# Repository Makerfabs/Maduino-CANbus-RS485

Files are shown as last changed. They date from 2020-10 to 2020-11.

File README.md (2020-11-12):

# Maduino Zero CANBUS
## Introduce

CAN-BUS is a common industrial communication bus because of its long travel distance, medium communication speed, and high reliability, it is the backbone of many protocols with applications in automation, industrial systems, building management. This Maduino Zero CAN-BUS based on SAMD21G18A, with the CAN controller MCP2515 and CAN transceiver MAX3051, to create a ready-to-use CAN-bus port. With this board, you can easily get/send your local data remotely with a standard CAN Bus. For example, you can collect local sensor data, using the Maduino zero ports, and send all the data to remote servers, to create remote-monitor with reliable CAN-Bus communication.<br>
[Makerfabs Wiki](https://www.makerfabs.com/wiki/index.php?title=Maduino_Zero_Canbus_with_RS485) <br>
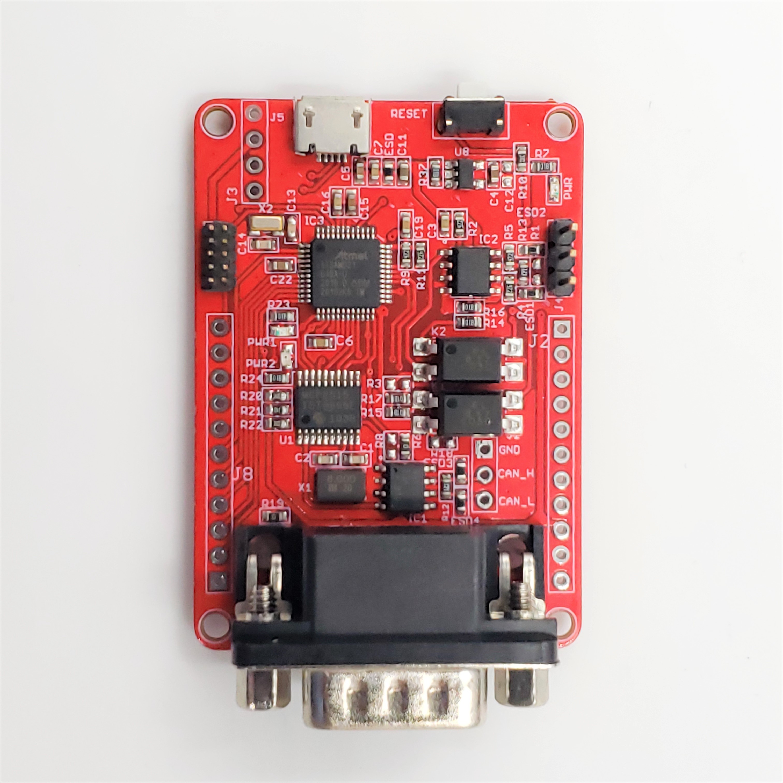
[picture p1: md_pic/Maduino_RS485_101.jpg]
<br/>

## Features

* ATMEL SAMD21G18A: 32-bit ARM® Cortex®-M0, Arduino Zero bootloader pre-loaded.<br>
* CAN-BUS/ RS-485.<br>
* Implements CAN V2.0 at 1M/s.<br>
* MCP2515 CAN Bus controller and MAX3051 CAN Bus transceiver.<br>
* Allows for Transmission Speeds Up to 16Mbps of RS-485.<br>
* Industrial standard 9 pins sub-D connector.<br>

## Usage

### Software setup

* After installed Arduino, there is no package to support the board (Arduino zero) that is needed to be installed.<br>
* select tools ->Board -> Board Manager, search "Arduino zero" and install "Arduino SAMD Boards".<br>
* Select Tools ->Board -> Arduino Zero (Native USB Port), select Tools -> Port -> com…<br>

### Test

* The sensors or devices which can carry on RS485 or CANbus are connected to the board through cables. in this project, use the same board instead of the device being tested, and connected two board by cables or Dupont Lines to check the communication between boards.<br>
* The pins connection is:<br>

|Maduino Zero CANbus with RS485 |Devices or sensors |
|---|---|
|GND |GND |
|RS485_A |RS485_A |
|RS485_B |RS485_B |
|CAN_H | CAN_H |
|CAN_L | CAN_L |

#### CANBUS
* One board upload the [CAN_Sender.ino](https://github.com/Makerfabs/Maduino-CANbus-RS485/blob/main/CAN_Sender/CAN_Sender.ino) , and the other upload the [CAN_Receiver.ino](https://github.com/Makerfabs/Maduino-CANbus-RS485/blob/main/CAN_Receiver/CAN_Receiver.ino). Both programs include the functions which can realize receiving and sending data in RS485 communication mode and CANBUS communication mode.<br>
* After the upload is successful, open the Serial Monitor and you can observe that the board is receiving and sending data cyclically through CANBUS. The green indicator light on the board will flash when data is received.<br>

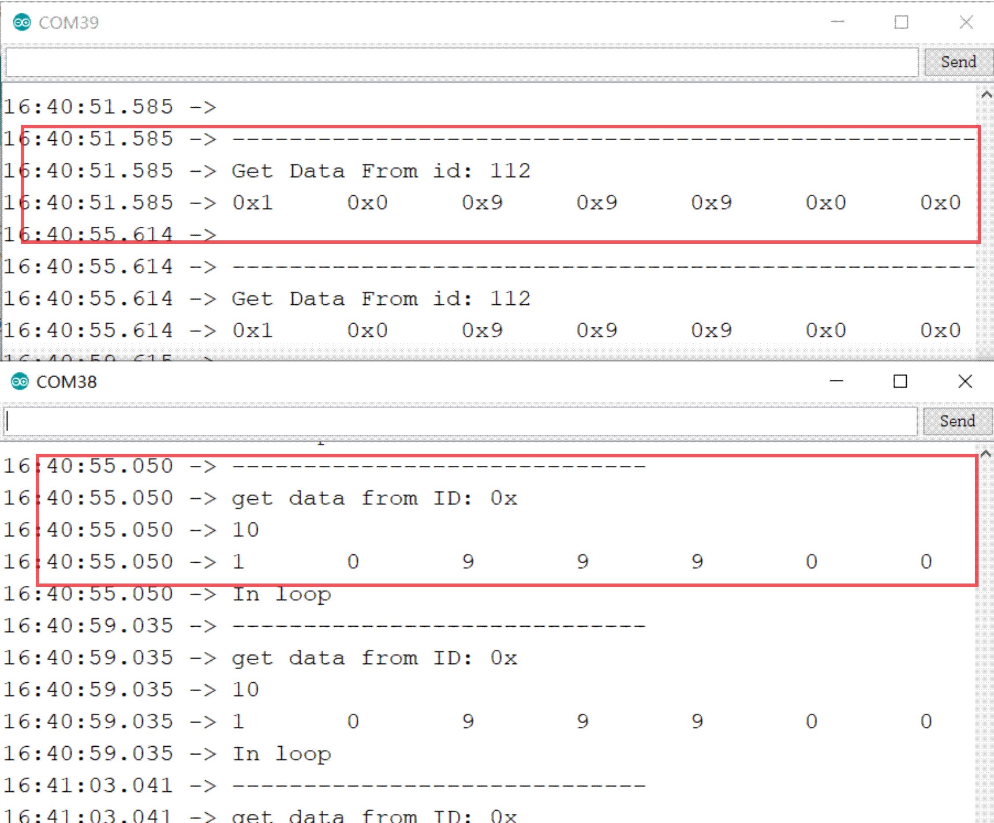
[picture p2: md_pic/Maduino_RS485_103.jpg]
<br/>

#### RS485
* Two boards upload the [RS485.ino](https://github.com/Makerfabs/Maduino-CANbus-RS485/blob/main/RS485/RS485.ino) ,
* After the upload is successful, open the Serial Monitor and send data through the Serial Monitor, and receive the data through RS485 communication on another board. The blue indicator light on the board will flash when data is received.<br>

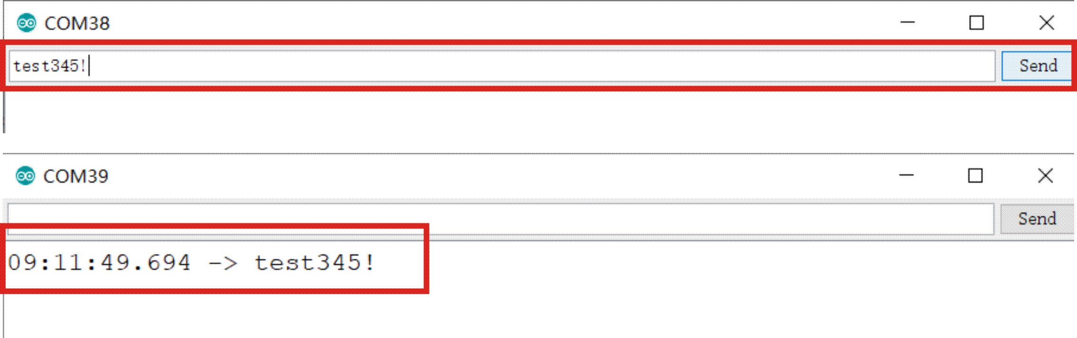
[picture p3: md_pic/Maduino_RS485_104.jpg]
<br/>
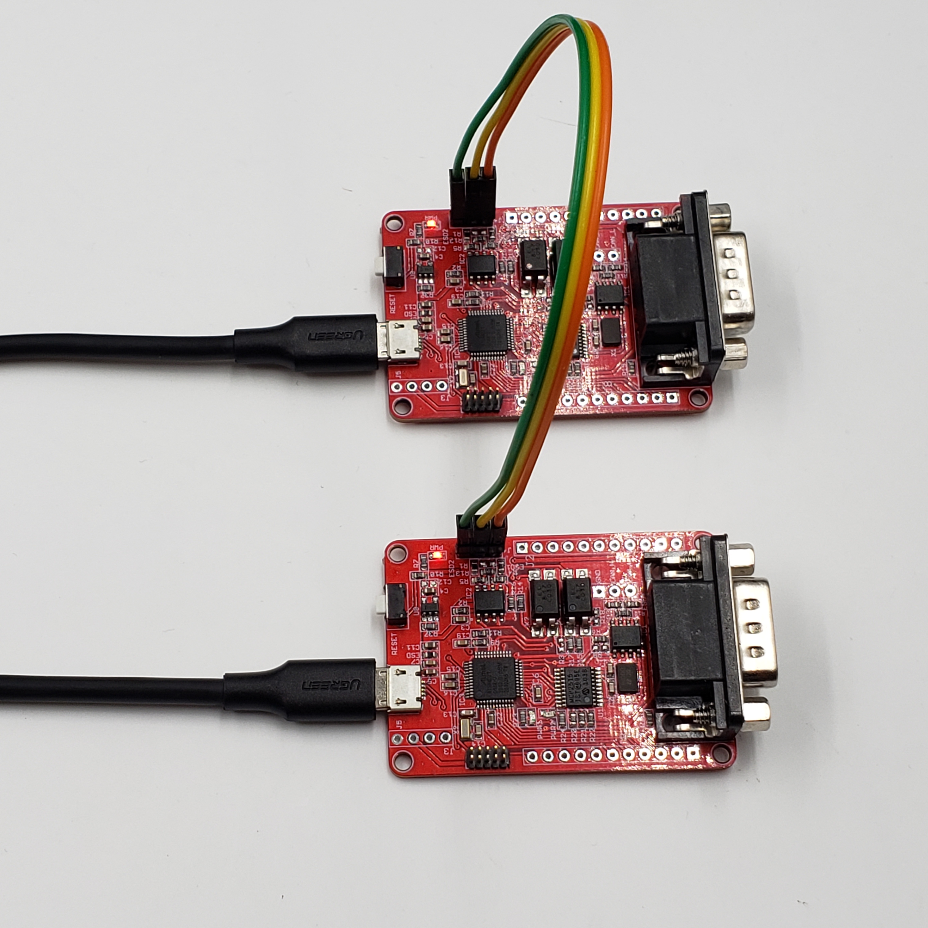
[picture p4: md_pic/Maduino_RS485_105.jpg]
<br/>

#### TEST_DHT11_OLED

This project is about data transmission via CANBUS. Use Maduino Zero CANBUS to collect temperature and humidity data and send it through CANBUS, and use the same module to receive and display the data.

<br/>

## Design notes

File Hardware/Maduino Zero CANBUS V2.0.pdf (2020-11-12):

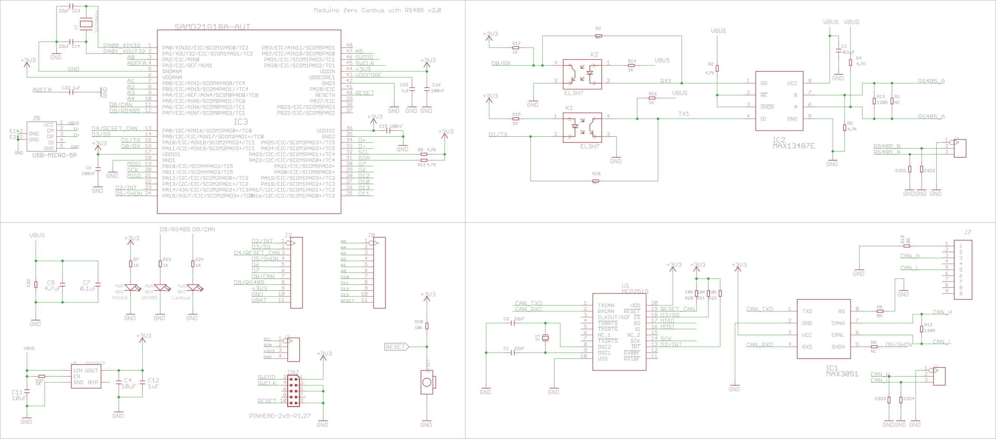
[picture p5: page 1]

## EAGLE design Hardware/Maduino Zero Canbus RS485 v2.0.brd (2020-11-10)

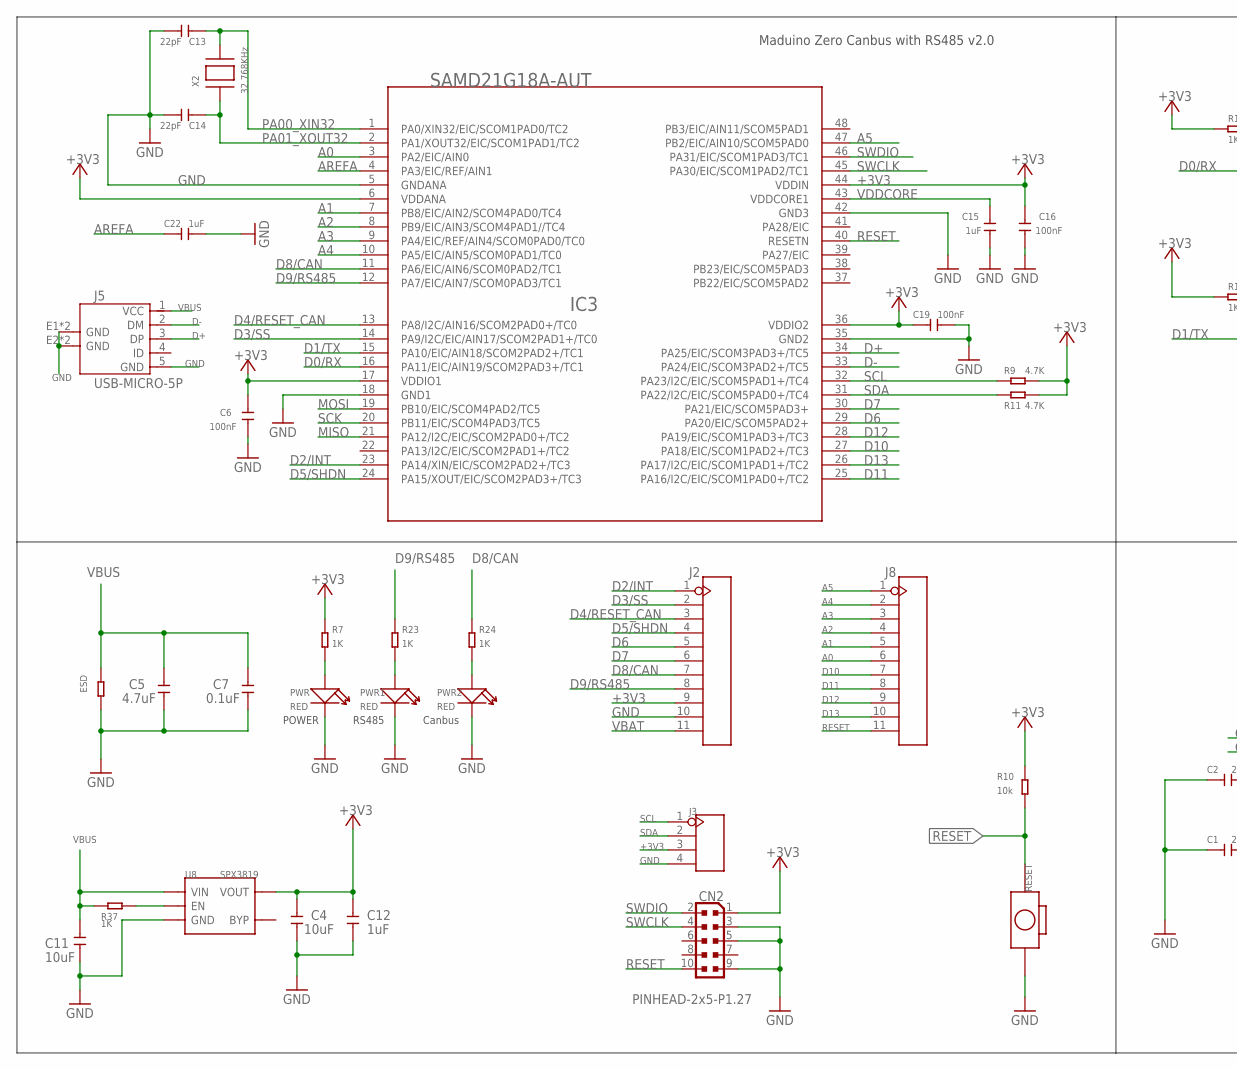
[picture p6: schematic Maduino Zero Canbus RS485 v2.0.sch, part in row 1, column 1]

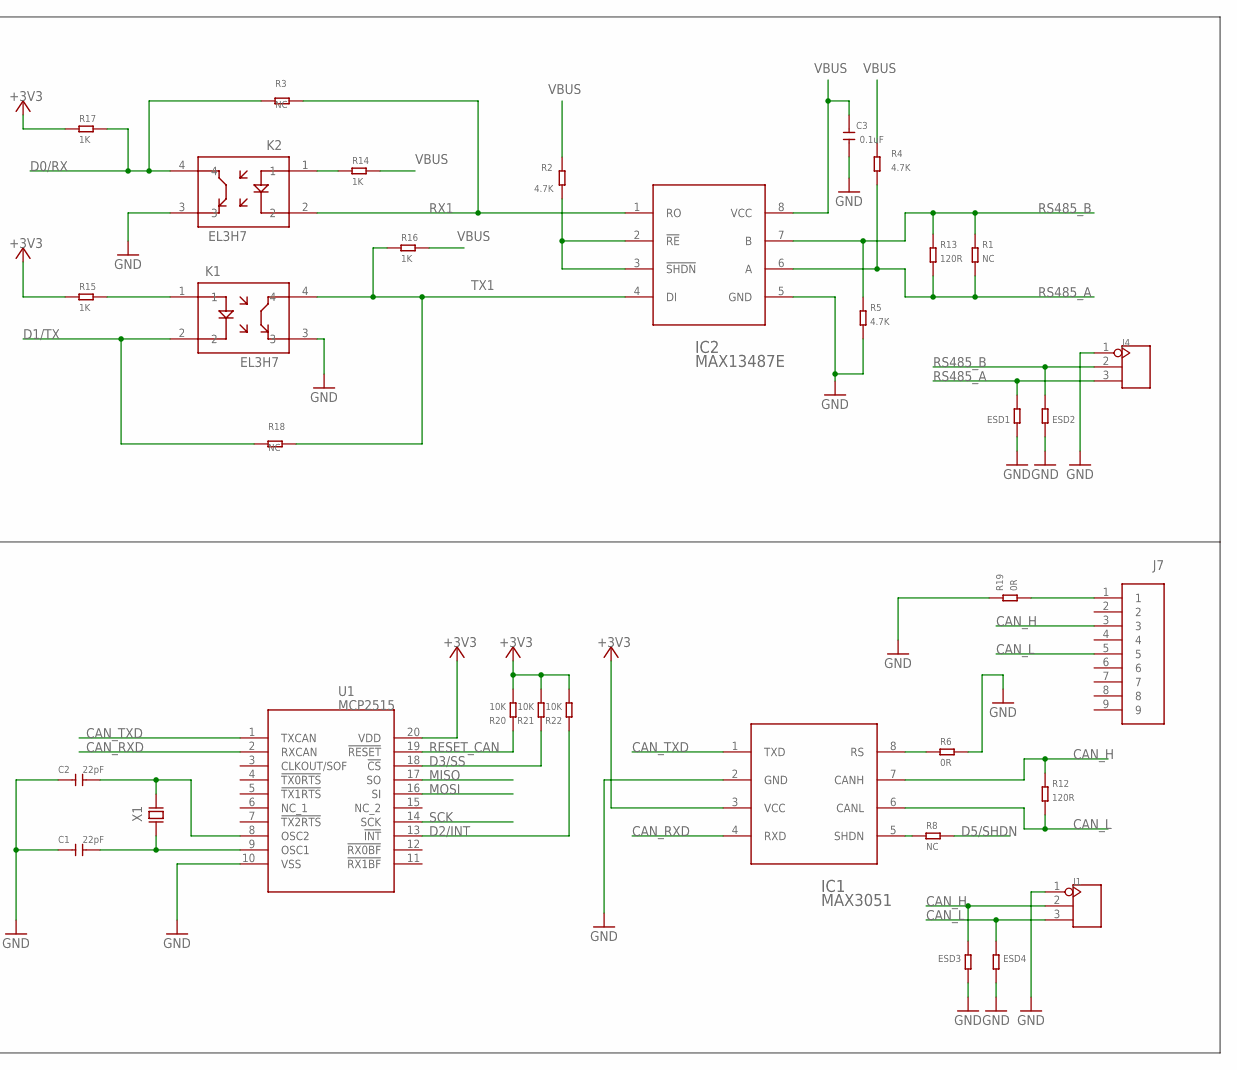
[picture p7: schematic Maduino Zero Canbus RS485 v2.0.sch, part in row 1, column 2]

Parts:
C1, C2, C13, C14: 22pF; 0603
C3, C7: 0.1uF; 0603
C4, C11: 10uF; 0603
C5: 4.7uF; 0603
C6, C16, C19: 100nF; 0603
C12, C15, C22: 1uF; 0603
CN2: PINHEAD-2x5-P1.27; PINHEAD_2X05_127
ESD, ESD1, ESD2: R-0603; R0603
ESD3, ESD4: NC; R0603
IC1: MAX3051; DIP8_MX3051
IC2: MAX13487E; DIP8_MAX13487
IC3: SAMD21G18A-AUT; TQFP48-7X7
J1, J4: HEADER-3P-2.54; 3P-2.54
J2, J8: HEADER-11P-2.54; 11P-2.54
J3: HEADER-4P-60/35MILROUND; 4P-65/35ROUND
J5: USB-MICRO-5P; MICRO-USB-5P
J7: DB9-90; DIP9-DB9-P2.77
K1, K2: EL3H7; SOP-4_P1.27
PWR, PWR1, PWR2: RED; LED-0603
R1, R3, R8, R18: NC; R0603
R2, R4, R5, R9, R11: 4.7K; R0603
R6, R19: 0R; R0603
R7, R14, R15, R16, R17, R23, R24, R37: 1K; R0603
R10: 10k; R0603
R12, R13: 120R; R0603
R20, R21, R22: 10K; R0603
RESET: BOTTON-2P-90D; 2P-7.62X3.56-90D
U1: MCP2515; SSOP-20
U8: SPX3819; SOT23-5
X1: XTAL-8MHZ; SMD-5032_2P_8M
X2: 32.768KHz; XTAL3215

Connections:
+3V3: C4.2, C6.2, C12.2, C16.1, C19.1, CN2.1, IC1.3 (VCC), IC3.6 (VDDANA), IC3.17 (VDDIO1), IC3.36 (VDDIO2), IC3.44 (VDDIN), J2.9, J3.3, R7.1, R9.2, R10.2, R11.2, R15.2, R17.2, R20.1, R21.1, R22.1, U1.20 (VDD), U8.5 (VOUT)
A0: IC3.3 (PA2/EIC/AIN0), J8.6
A1: IC3.7 (PB8/EIC/AIN2/SCOM4PAD0/TC4), J8.5
A2: IC3.8 (PB9/EIC/AIN3/SCOM4PAD1//TC4), J8.4
A3: IC3.9 (PA4/EIC/REF/AIN4/SCOM0PAD0/TC0), J8.3
A4: IC3.10 (PA5/EIC/AIN5/SCOM0PAD1/TC0), J8.2
A5: IC3.47 (PB2/EIC/AIN10/SCOM5PAD0), J8.1
AREFA: C22.1, IC3.4 (PA3/EIC/REF/AIN1)
CAN_H: ESD3.1, IC1.7 (CANH), J1.2, J7.3, R12.1
CAN_L: ESD4.1, IC1.6 (CANL), J1.3, J7.5, R12.2
CAN_RXD: IC1.4 (RXD), U1.2 (RXCAN)
CAN_TXD: IC1.1 (TXD), U1.1 (TXCAN)
D0/RX: IC3.16 (PA11/EIC/AIN19/SCOM2PAD3+/TC1), K2.4, R3.2, R17.1
D1/TX: IC3.15 (PA10/EIC/AIN18/SCOM2PAD2+/TC1), K1.2, R18.2
D2/INT: IC3.23 (PA14/XIN/EIC/SCOM2PAD2+/TC3), J2.1, R22.2, U1.13 (!INT)
D3/SS: IC3.14 (PA9/I2C/EIC/AIN17/SCOM2PAD1+/TC0), J2.2, R21.2, U1.18 (!CS)
D4/RESET_CAN: IC3.13 (PA8/I2C/AIN16/SCOM2PAD0+/TC0), J2.3
D5/SHDN: IC3.24 (PA15/XOUT/EIC/SCOM2PAD3+/TC3), J2.4, R8.1
D6: IC3.29 (PA20/EIC/SCOM5PAD2+), J2.5
D7: IC3.30 (PA21/EIC/SCOM5PAD3+), J2.6
D8/CAN: IC3.11 (PA6/EIC/AIN6/SCOM0PAD2/TC1), J2.7, R24.1
D9/RS485: IC3.12 (PA7/EIC/AIN7/SCOM0PAD3/TC1), J2.8, R23.1
D10: IC3.27 (PA18/EIC/SCOM1PAD2+/TC3), J8.7
D11: IC3.25 (PA16/I2C/EIC/SCOM1PAD0+/TC2), J8.8
D12: IC3.28 (PA19/EIC/SCOM1PAD3+/TC3), J8.9
D13: IC3.26 (PA17/I2C/EIC/SCOM1PAD1+/TC2), J8.10
D+: IC3.34 (PA25/EIC/SCOM3PAD3+/TC5), J5.3 (DP)
D-: IC3.33 (PA24/EIC/SCOM3PAD2+/TC5), J5.2 (DM)
GND: C1.1, C2.1, C3.1, C4.1, C5.1, C6.1, C7.1, C11.1, C12.1, C13.2, C14.2, C15.2, C16.2, C19.2, C22.2, CN2.3, CN2.5, CN2.9, ESD.2, ESD1.1, ESD2.1, ESD3.2, ESD4.2, IC1.2 (GND), IC2.5 (GND), IC3.5 (GNDANA), IC3.18 (GND1), IC3.35 (GND2), IC3.42 (GND3), J1.1, J2.10, J3.4, J4.1, J5.5 (GND), J5.E1 (GND), J5.E2 (GND), J5.P1 (GND), J5.P2 (GND), K1.3, K2.3, PWR.-, PWR1.-, PWR2.-, R5.1, R6.1, R19.2, RESET.P$2 (2), U1.10 (VSS), U8.2 (GND)
MISO: IC3.21 (PA12/I2C/EIC/SCOM2PAD0+/TC2), U1.17 (SO)
MOSI: IC3.19 (PB10/EIC/SCOM4PAD2/TC5), U1.16 (SI)
unnamed: K2.1, R14.2
unnamed: PWR.+, R7.2
unnamed: C2.2, U1.8 (OSC2), X1.2
unnamed: C1.2, U1.9 (OSC1), X1.1
unnamed: K1.1, R15.1
unnamed: J7.1, R19.1
unnamed: PWR1.+, R23.2
unnamed: PWR2.+, R24.2
unnamed: IC1.8 (RS), R6.2
unnamed: IC1.5 (SHDN), R8.2
unnamed: R37.2, U8.3 (EN)
unnamed: IC2.2 (!RE), IC2.3 (!SHDN), R2.1
PA00_XIN32: C13.1, IC3.1 (PA0/XIN32/EIC/SCOM1PAD0/TC2), X2.P$2
PA01_XOUT32: C14.1, IC3.2 (PA1/XOUT32/EIC/SCOM1PAD1/TC2), X2.P$1
RESET: CN2.10, IC3.40 (RESETN), J8.11, R10.1, RESET.P$1 (1)
RESET_CAN: R20.2, U1.19 (!RESET)
RS485_A: ESD1.2, IC2.6 (A), J4.3, R1.1, R4.1, R13.1
RS485_B: ESD2.2, IC2.7 (B), J4.2, R1.2, R5.2, R13.2
RX1: IC2.1 (RO), K2.2, R3.1
SCK: IC3.20 (PB11/EIC/SCOM4PAD3/TC5), U1.14 (SCK)
SCL: IC3.32 (PA23/I2C/EIC/SCOM5PAD1+/TC4), J3.1, R9.1
SDA: IC3.31 (PA22/I2C/EIC/SCOM5PAD0+/TC4), J3.2, R11.1
SWCLK: CN2.4, IC3.45 (PA30/EIC/SCOM1PAD2/TC1)
SWDIO: CN2.2, IC3.46 (PA31/EIC/SCOM1PAD3/TC1)
TX1: IC2.4 (DI), K1.4, R16.2, R18.1
VBAT: J2.11
VBUS: C3.2, C5.2, C7.2, C11.2, ESD.1, IC2.8 (VCC), J5.1 (VCC), R2.2, R4.2, R14.1, R16.1, R37.1, U8.1 (VIN)
VDDCORE: C15.1, IC3.43 (VDDCORE1)

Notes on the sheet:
Maduino Zero Canbus with RS485 v2.0
POWER
RS485
Canbus

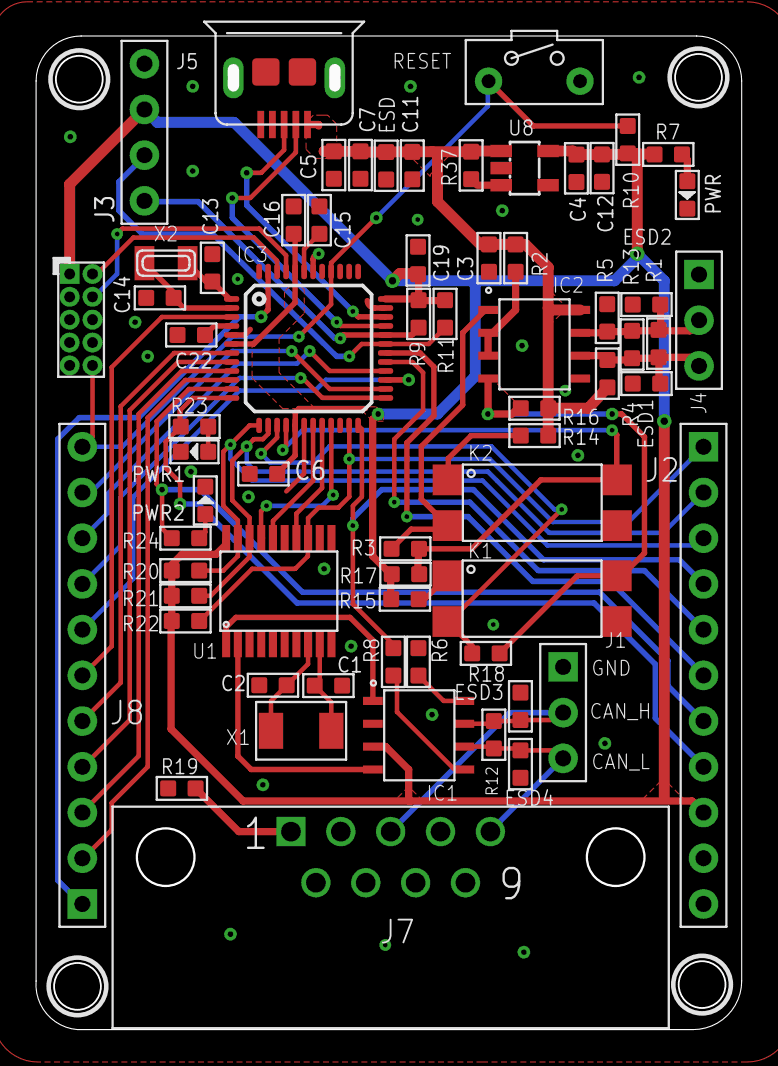
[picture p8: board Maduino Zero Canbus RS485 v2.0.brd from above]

Board: 2 copper layers, 39.2 x 55.2 mm, 67 parts (1 on the bottom side), 58 nets.

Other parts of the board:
U$1: MAKERFABS_0.3

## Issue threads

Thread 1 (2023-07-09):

Has this been tested against anything other than itself

eliotmansfield, 2023-07-09:
If I set the speed to 500kb/s and connect it to another arduino running canhacker, i have to set the speed to 250kb/s - also if i connect it to my car, again I have to set the ECU to 250kbs/s but the maduino to 500kb/s - also the can_receiver code never receives anything (which uses interrupts) but the can_sender does work in both directions to canhacker and my car ECU - but i have to set it to the wrong speed for it to work.

My module was bought from makerfabs tindie store.

HazzyDave, 2024-07-22:
You have this issue if you set for 16MHZ clock speed. You need to set it for 8MHZ.

HazzyDave, 2024-07-23:
while (CAN_OK != CAN.begin(CAN_500KBPS,MCP_8MHz)

HazzyDave, 2024-07-26:
Mate you can close this issue if it fixed the problem

Closed 2024-07-28.

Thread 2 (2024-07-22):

CAN speeds are not correct

HazzyDave, 2024-07-22:
If I set the speed to 500K my reciever needs to be set to 250K. If i set it to 1000K then my reciever gets it at 500K.

I have tried the example and another sketch that works perfect on my other boards but this one has the same result of the defined speed ending being cut in half when it sends...

HazzyDave, 2024-07-22:
Although not stated anywhere or available in the dem sketch you have to be set to 8MHZ not 16MHZ for the speed to be correct.

eliotmansfield, 2024-07-22:
this line in mcp2515.h?

`"#define MCP2515_DEFAULT_CLOCK_FREQUENCY 16e6" `

HazzyDave, 2024-07-22:
I actrually used a different set of examples designed for the 2515 that allows you to set the clock speed in the init line of the sketch. I didn't look through thier examples to solve it.

The line you posted looks like it could be the fix. Although I have contemplated removing their 8MHZ crystal and swapping in a 16MHZ.
I am using Fowlers duo can library since most of what I do is with dual can bus.  I made a quick mod to the sketch below to test with  a can sniffer. The print commands don't work but the board works as it should.

// CAN Send Example
//

#include <mcp_can.h>
#include <SPI.h>
#define SERIAL SerialUSB
MCP_CAN CAN0(3);     // Set CS

void setup()
{
  Serial.begin(115200);
  Serial1.begin(115200);
  // Initialize MCP2515 running at 8MHz with a baudrate of 1000kb/s (1MBs) and the masks and filters disabled.
  if(CAN0.begin(MCP_ANY, CAN_1000KBPS, MCP_8MHZ) == CAN_OK) Serial1.println("MCP2515 Initialized Successfully!");
  else Serial1.println("Error Initializing MCP2515...");

  CAN0.setMode(MCP_NORMAL);   // Change to normal mode to allow messages to be transmitted
}

byte data[8] = {0x00, 0x01, 0x02, 0x03, 0x04, 0x05, 0x06, 0x07};

void loop()
{
  // send data:  ID = 0x100, Standard CAN Frame, Data length = 8 bytes, 'data' = array of data bytes to send
  byte sndStat = CAN0.sendMsgBuf(0x100, 0, 8, data);
  if(sndStat == CAN_OK){
    Serial1.println("Message Sent Successfully!");
  } else {
    Serial1.println("Error Sending Message...");
  }
  delay(50);   // send data per 50ms

HazzyDave, 2024-07-23:
Here you go mate. Just set your can up as follows. For some reason they didn't include the clock in the setup. After checking the source code it made sense.

while (CAN_OK != CAN.begin(CAN_500KBPS,MCP_8MHz)

Closed 2024-07-22.

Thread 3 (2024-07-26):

Leaving review here with what I see as poor build.  since they don't post real revies on their site.

HazzyDave, 2024-07-26:
First of all the sketches don't declare the clock speed. So if you don't know better or figure it out the BUS speed will be wrong. Youhave to add it yourself to the sketch to correct.

2nd they didn't allow you to power to the board from the DB9 to 12 volts.. I mean really... You have to add a power source which just seems to miss the mark for any embedded soloution.

3rd and HUGE 3rd. They didn't break out the SPI. That virtually made this board usless to me and a waste of money. I wanted to add a second CAN but I can't unless I can solder directly to the pins on the chip. This will also mean you can't add an SPI driven display or SD card.

Lastly they don't seem to allow negative reviews on their site as this is not the first one I have posted so I will make a goole review or just start posting this onto the forums and GIT hub.

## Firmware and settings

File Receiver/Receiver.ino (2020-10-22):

#include <SPI.h>
#include "mcp_can.h"

#define SERIAL SerialUSB

const int SPI_CS_PIN = 3;
const int RS485_LED = 9;
const int CAN_LED = 8;


MCP_CAN CAN(SPI_CS_PIN);                                    // Set CS pin

const byte interruptPin = 2;
unsigned char flagRecv = 0;
unsigned char len = 0;
unsigned char buf[8];
char str[20];

void setup() {
    SERIAL.begin(9600);
    Serial1.begin(9600);
    pinMode(RS485_LED,OUTPUT);
    pinMode(CAN_LED,OUTPUT);
    delay(3000);
    while (CAN_OK != CAN.begin(CAN_500KBPS)) {            // init can bus : baudrate = 500k
        SERIAL.println("CAN BUS Shield init fail");
        SERIAL.println(" Init CAN BUS Shield again");
        delay(100);
    }
    SERIAL.println("CAN BUS Shield init ok!");

    attachInterrupt(digitalPinToInterrupt(interruptPin), MCP2515_ISR, FALLING); // start interrupt


    /*
        set mask, set both the mask to 0x3ff
    */
    CAN.init_Mask(0, 0, 0x3ff);                         // there are 2 mask in mcp2515, you need to set both of them
    CAN.init_Mask(1, 0, 0x3ff);

    /*
        set filter, we can receive id from 0x04 ~ 0x09
    */
    CAN.init_Filt(0, 0, 0x70);                          // there are 6 filter in mcp2515
    /*CAN.init_Filt(1, 0, 0x05);                          // there are 6 filter in mcp2515

    CAN.init_Filt(2, 0, 0x06);                          // there are 6 filter in mcp2515
    CAN.init_Filt(3, 0, 0x07);                          // there are 6 filter in mcp2515
    CAN.init_Filt(4, 0, 0x08);                          // there are 6 filter in mcp2515
    CAN.init_Filt(5, 0, 0x09);   */                       // there are 6 filter in mcp2515
    SERIAL.println(" Init CAN BUS ok----");
}

void MCP2515_ISR() {
    flagRecv = 1;
}


void loop() {
/*********************  CANBUS  ***************************/
    if (flagRecv) {                // check if get data
        flagRecv = 0;                // clear flag
        CAN.readMsgBuf(&len, buf);    // read data,  len: data length, buf: data buf
        digitalWrite(CAN_LED,HIGH);
        SERIAL.println("\r\n------------------------------------------------------------------");
        SERIAL.print("Get Data From id: ");
        SERIAL.println(CAN.getCanId());
        for (int i = 0; i < len; i++) { // print the data
            SERIAL.print("0x");
            SERIAL.print(buf[i], HEX);
            SERIAL.print("\t");
        }
        SERIAL.println();

    }
    digitalWrite(CAN_LED,LOW);
    // send the message
    CAN.sendMsgBuf(0x10, 0, 8, buf);
    delay(1000);    

/***************  RS485  *********************/
     //get what form serial send to USB serial
    while (Serial1.available() > 0) {
      digitalWrite(RS485_LED,HIGH);  
      SerialUSB.write(Serial1.read()); 
      yield();
    }
    //get what form USB serial send to serial
    while (SerialUSB.available() > 0) {
      Serial1.write(SerialUSB.read());
      yield();
    }
    digitalWrite(RS485_LED,LOW);
}

/*********************************************************************************************************
    END FILE
*********************************************************************************************************/

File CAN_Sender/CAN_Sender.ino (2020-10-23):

#include "mcp_can.h"
#include <SPI.h>

#define SERIAL SerialUSB


const int SPI_CS_PIN = 3;
const int CAN_LED = 8;

MCP_CAN CAN(SPI_CS_PIN);                                    // Set CS pin

void setup() {
    SERIAL.begin(9600);
    Serial1.begin(9600);
    pinMode(CAN_LED,OUTPUT);
    while (CAN_OK != CAN.begin(CAN_500KBPS)) {            // init can bus : baudrate = 500k
        SERIAL.println("CAN BUS Shield init fail");
        SERIAL.println(" Init CAN BUS Shield again");
        delay(100);
    }
    SERIAL.println("CAN BUS Shield init ok!");
}

unsigned char stmp[8] = {1, 0, 9, 9, 9, 0, 0, 7};

void loop() {
    SERIAL.println("In loop");
/************************  CANBUS  ********************************/ 
    // send data:  id = 0x70, standard frame, data len = 8, stmp: data buf
    CAN.sendMsgBuf(0x70, 0, 8, stmp);
    delay(4000);                       // send data once per second

    unsigned char len = 0;
    unsigned char buf[8];

    if (CAN_MSGAVAIL == CAN.checkReceive()) {         // check if data coming
        CAN.readMsgBuf(&len, buf);    // read data,  len: data length, buf: data buf
        digitalWrite(CAN_LED,HIGH);
        unsigned long canId = CAN.getCanId();
        SERIAL.println("-----------------------------");
        SERIAL.println("get data from ID: 0x");
        SERIAL.println(canId, HEX);
        for (int i = 0; i < len; i++) { // print the data
            SERIAL.print(buf[i]);
            SERIAL.print("\t");            
        }
        SERIAL.println();
        delay(300);
    }
    digitalWrite(CAN_LED,LOW);

}

/*********************************************************************************************************
    END FILE
*********************************************************************************************************/

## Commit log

2020-10-22 add hardware
    [Maduino Zero Canbus RS485 v1.1.brd, Maduino Zero Canbus RS485 v1.1.sch]
2020-10-23 hardware updata
    [Maduino Zero Canbus RS485 v1.1.brd]
